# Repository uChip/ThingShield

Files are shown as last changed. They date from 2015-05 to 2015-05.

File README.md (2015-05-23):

# ThingShield
The [SparkFun Thing (WRL-13231)](https://www.sparkfun.com/products/13231) is a board for creating Internet of Things devices based on the ESP-8266 WiFi microcontroller.  This repo contains "shield" designs in the form factor and pinout of the Thing.

ThingShield_Bare is a set (schematic and board) of design files that have the basic board outline and pinout.  Use this as the start of your own shield design.  I have left a voltage regulator circuit on the board for power.  The regulator is easily deleted if it does not meet your needs.

ThingShield_Proto is a board with prototyping area.  Again there is a voltage regulator on the shield board.  The regulator can be omitted if your design does not need much current.  Instead you can draw power directly from the Thing board.

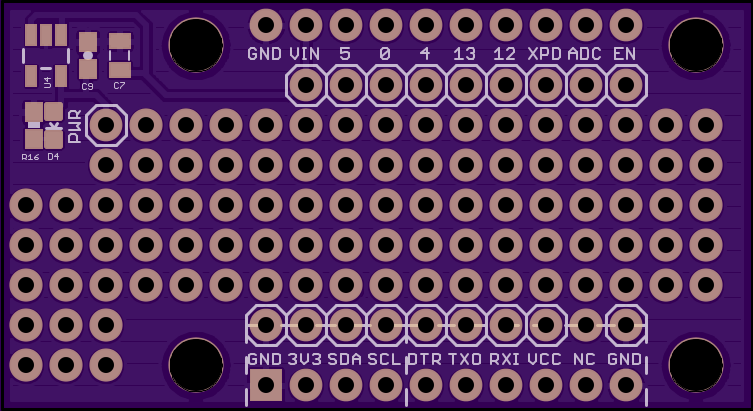
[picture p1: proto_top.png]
Thing Proto Board


Bare circuit boards of the proto shield can be ordered from [OSH Park](https://oshpark.com/shared_projects/OK6ncANs)

Boards propogate the CC license of the parent SparkFun board.  No liability accepted.

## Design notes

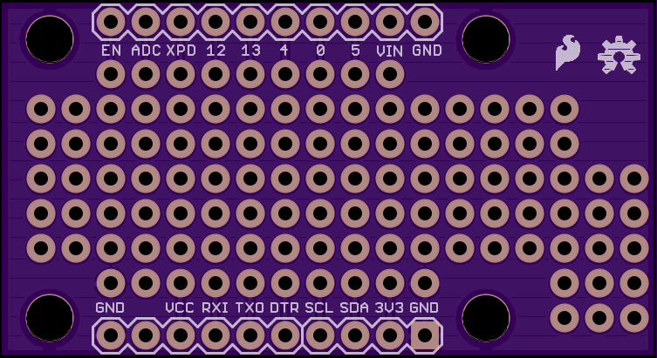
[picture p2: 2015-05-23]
proto_bottom.png

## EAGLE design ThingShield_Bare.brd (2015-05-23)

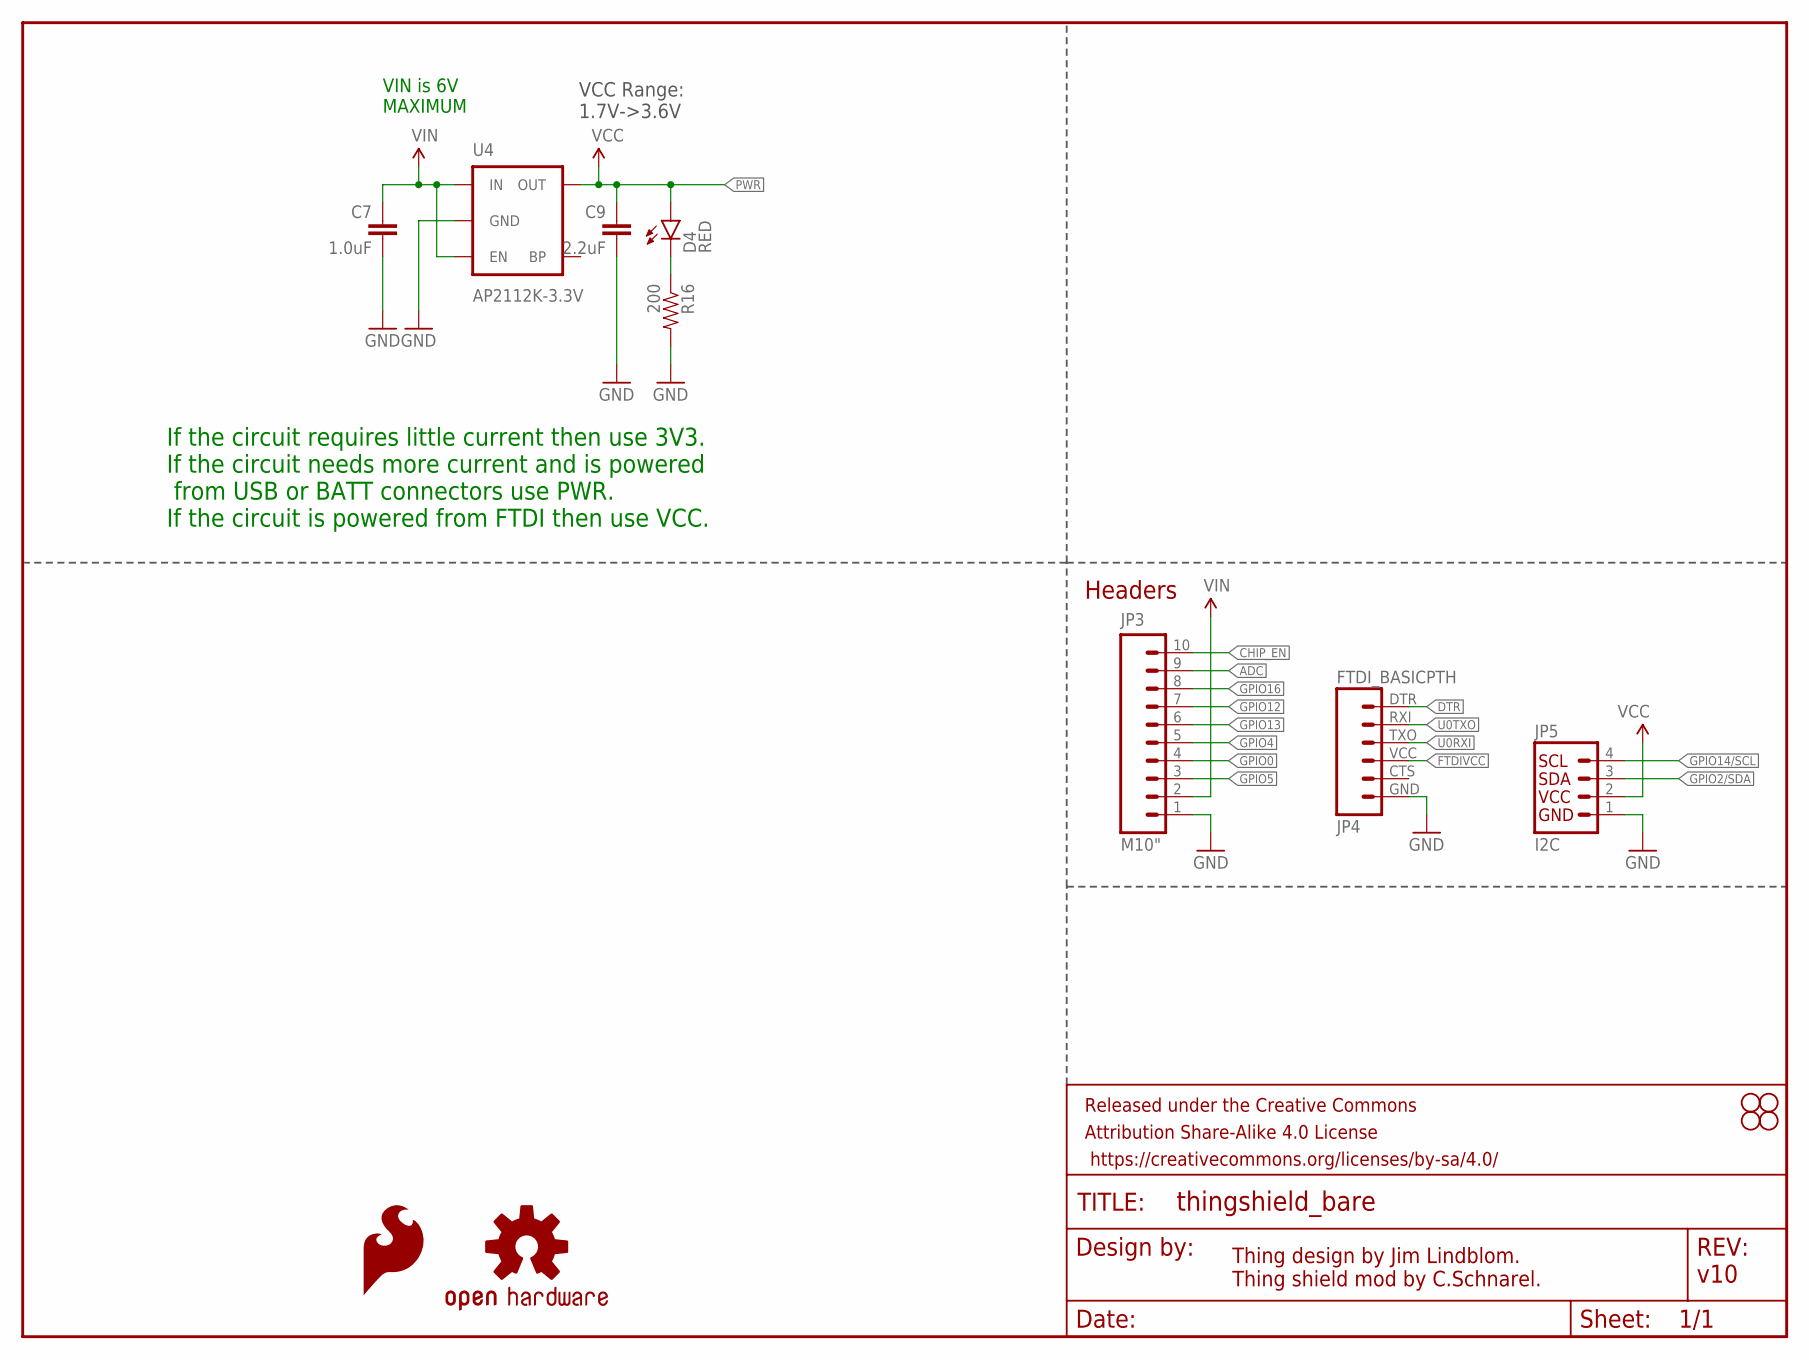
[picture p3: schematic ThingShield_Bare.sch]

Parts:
C7: 1.0uF; 0805
C9: 2.2uF; 0603-CAP
D4: RED; LED-0603
FRAME1: FRAME-LETTER; CREATIVE_COMMONS
JP3: M10"; 1X10
JP4: FTDI_BASICPTH; FTDI_BASIC
JP5: I2C; 1X04
LOGO3: SFE_LOGO_FLAME.1_INCH; SFE_LOGO_FLAME_.1
LOGO4: OSHW-LOGOS; OSHW-LOGO-S
R16: 200; 0603-RES
STANDOFF1, STANDOFF2, STANDOFF3, STANDOFF4: STAND-OFF
U4: AP2112K-3.3V; SOT23-5

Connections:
ADC: JP3.9
CHIP_EN: JP3.10
DTR: JP4.DTR (1)
FTDIVCC: JP4.VCC (4)
GND: C7.2, C9.2, JP3.1, JP4.GND (6), JP5.1, R16.2, U4.2 (GND)
GPIO0: JP3.4
GPIO2/SDA: JP5.3
GPIO4: JP3.5
GPIO5: JP3.3
GPIO12: JP3.7
GPIO13: JP3.6
GPIO14/SCL: JP5.4
GPIO16: JP3.8
unnamed: D4.C, R16.1
PWR: C9.1, D4.A, U4.5 (OUT)
U0RXI: JP4.TXO (3)
U0TXO: JP4.RXI (2)
VCC: JP5.2
VIN: C7.1, JP3.2, U4.1 (IN), U4.3 (EN)

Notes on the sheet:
Thing design by Jim Lindblom. Thing shield mod by C.Schnarel.
Headers
v10
VCC Range: 1.7V->3.6V
If the circuit requires little current then use 3V3. If the circuit needs more current and is powered from USB or BATT connectors use PWR. If the circuit is powered from FTDI then use VCC.
VIN is 6V MAXIMUM

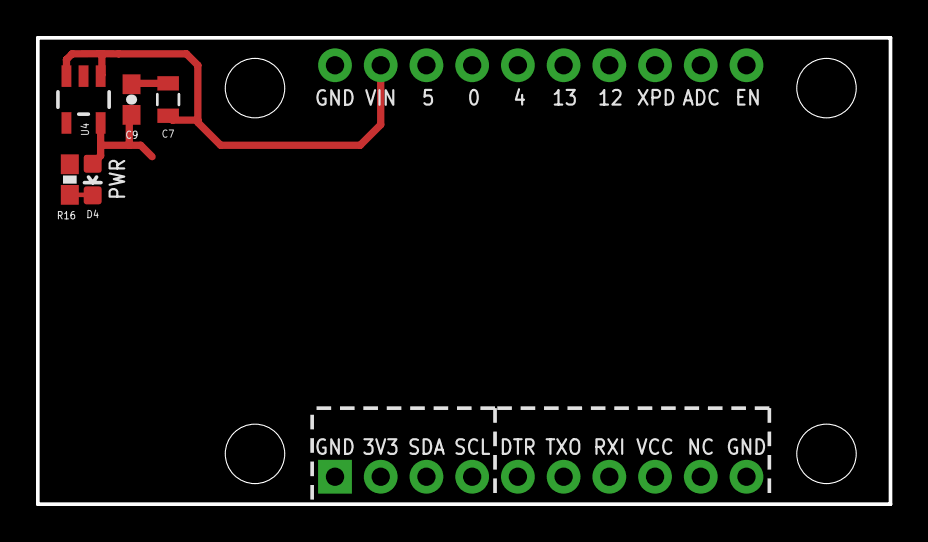
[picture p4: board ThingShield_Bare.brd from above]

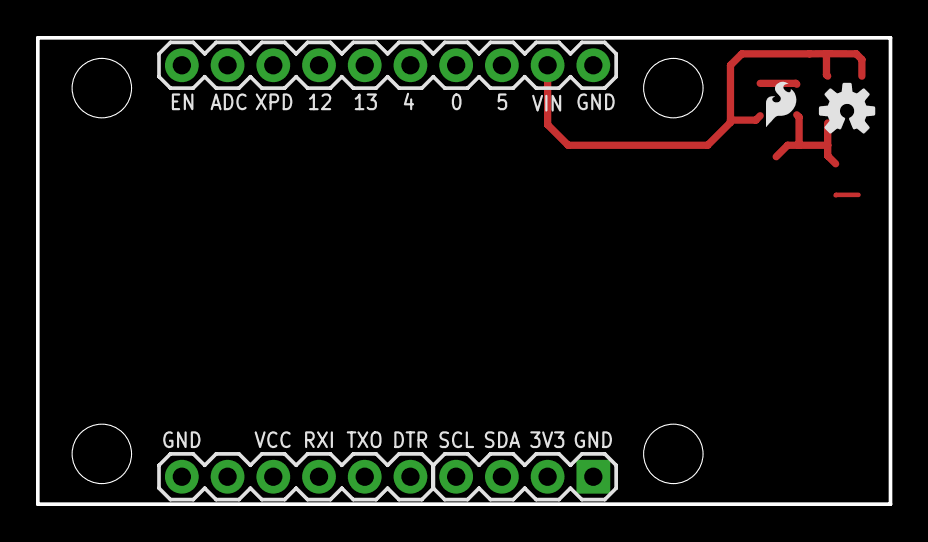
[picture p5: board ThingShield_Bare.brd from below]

Board: 2 copper layers, 47.4 x 25.9 mm, 15 parts (5 on the bottom side), 4 nets.

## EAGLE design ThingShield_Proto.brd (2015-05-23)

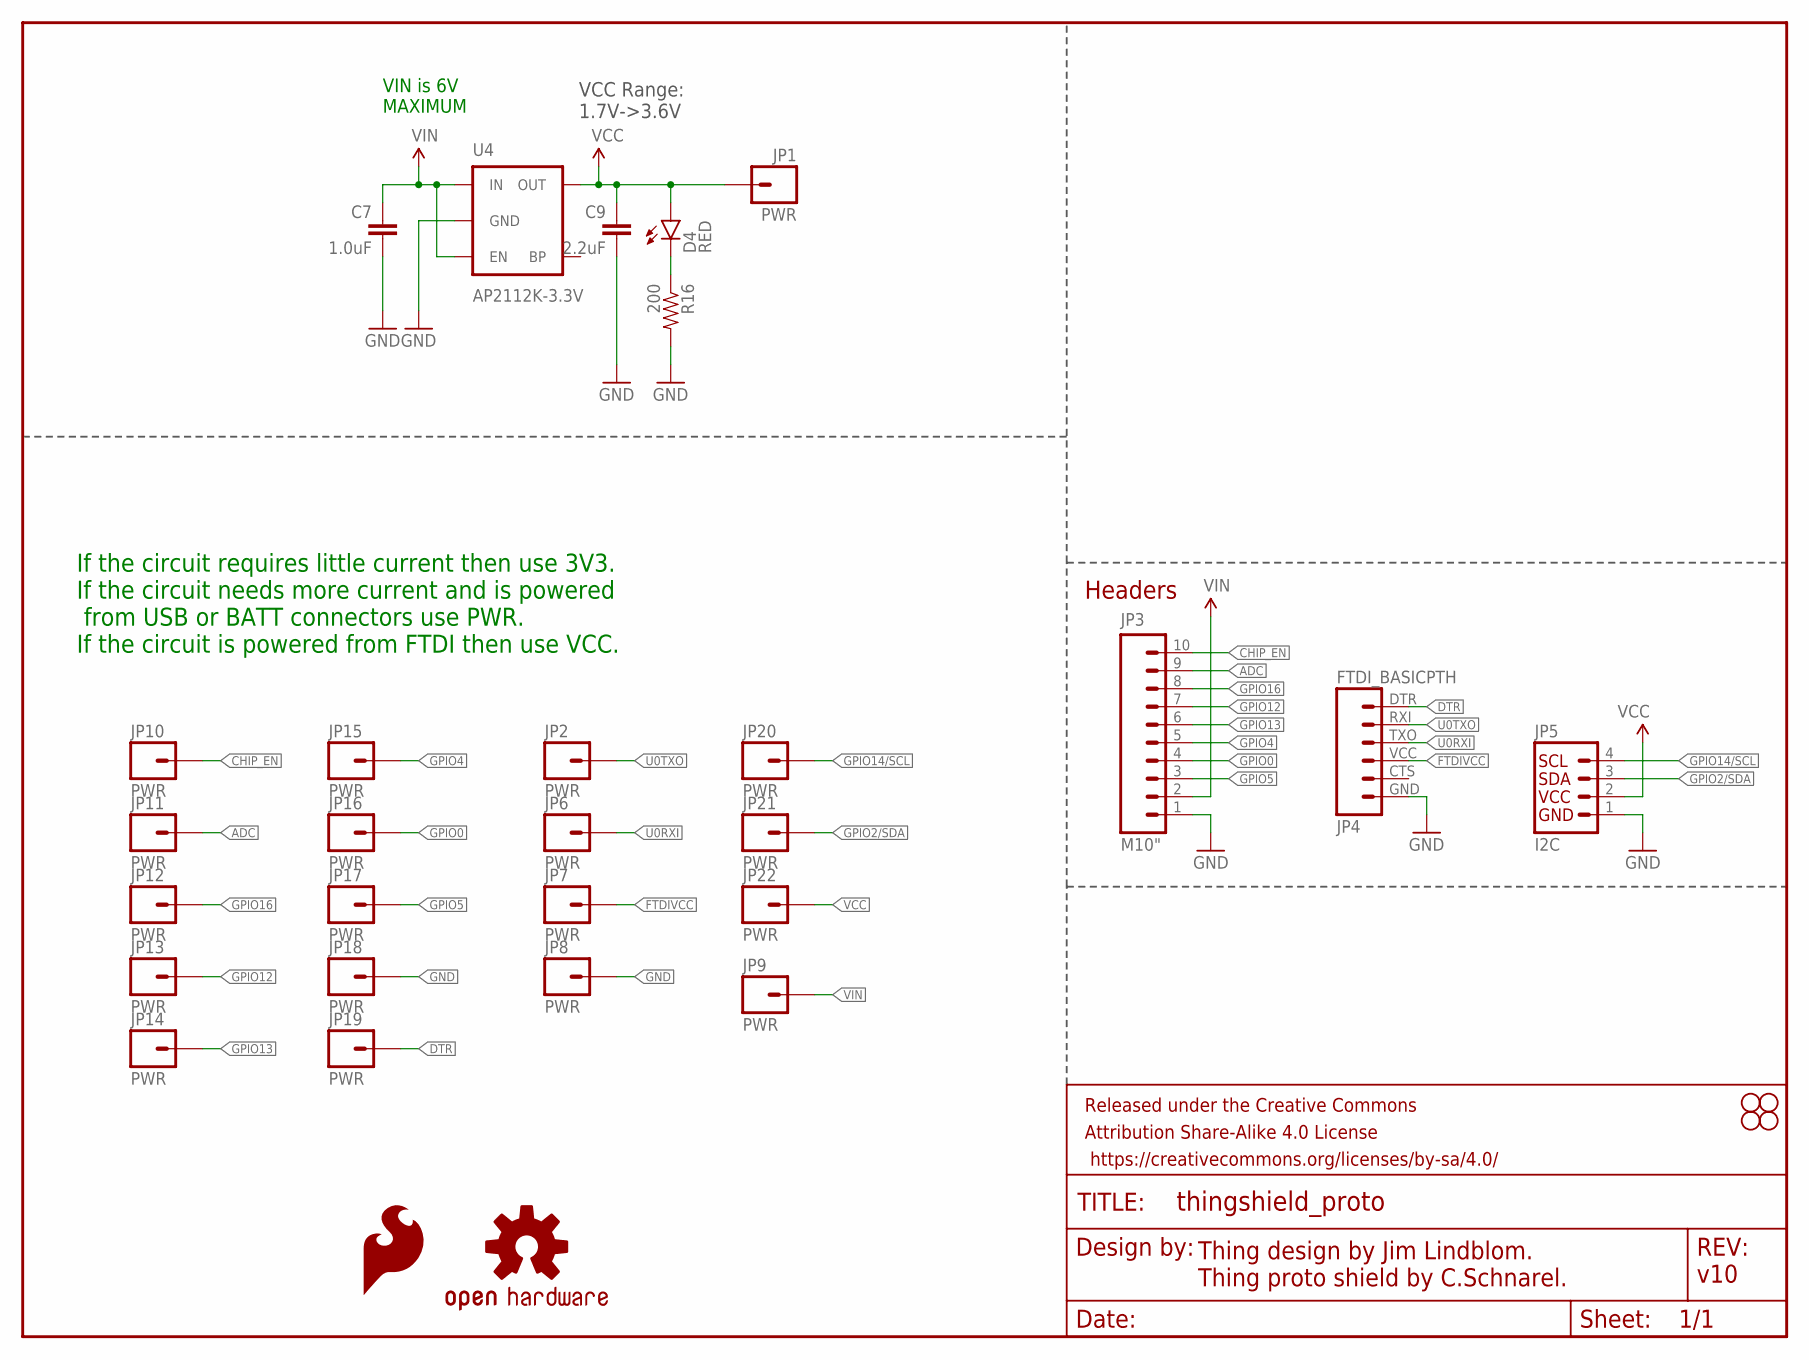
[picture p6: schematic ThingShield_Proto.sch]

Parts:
C7: 1.0uF; 0805
C9: 2.2uF; 0603-CAP
D4: RED; LED-0603
FRAME1: FRAME-LETTER; CREATIVE_COMMONS
JP1, JP2, JP6, JP7, JP8, JP9, JP10, JP11, JP12, JP13, JP14, JP15, JP16, JP17, JP18, JP19, JP20, JP21, JP22: PWR; 1X01
JP3: M10"; 1X10
JP4: FTDI_BASICPTH; FTDI_BASIC
JP5: I2C; 1X04
LOGO3: SFE_LOGO_FLAME.1_INCH; SFE_LOGO_FLAME_.1
LOGO4: OSHW-LOGOS; OSHW-LOGO-S
R16: 200; 0603-RES
STANDOFF1, STANDOFF2, STANDOFF3, STANDOFF4: STAND-OFF
U4: AP2112K-3.3V; SOT23-5

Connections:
ADC: JP3.9, JP11.1
CHIP_EN: JP3.10, JP10.1
DTR: JP4.DTR (1), JP19.1
FTDIVCC: JP4.VCC (4), JP7.1
GND: C7.2, C9.2, JP3.1, JP4.GND (6), JP5.1, JP8.1, JP18.1, R16.2, U4.2 (GND)
GPIO0: JP3.4, JP16.1
GPIO2/SDA: JP5.3, JP21.1
GPIO4: JP3.5, JP15.1
GPIO5: JP3.3, JP17.1
GPIO12: JP3.7, JP13.1
GPIO13: JP3.6, JP14.1
GPIO14/SCL: JP5.4, JP20.1
GPIO16: JP3.8, JP12.1
unnamed: D4.C, R16.1
PWR: C9.1, D4.A, JP1.1, U4.5 (OUT)
U0RXI: JP4.TXO (3), JP6.1
U0TXO: JP2.1, JP4.RXI (2)
VCC: JP5.2, JP22.1
VIN: C7.1, JP3.2, JP9.1, U4.1 (IN), U4.3 (EN)

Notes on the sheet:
Thing design by Jim Lindblom. Thing proto shield by C.Schnarel.
Headers
v10
VCC Range: 1.7V->3.6V
If the circuit requires little current then use 3V3. If the circuit needs more current and is powered from USB or BATT connectors use PWR. If the circuit is powered from FTDI then use VCC.
VIN is 6V MAXIMUM

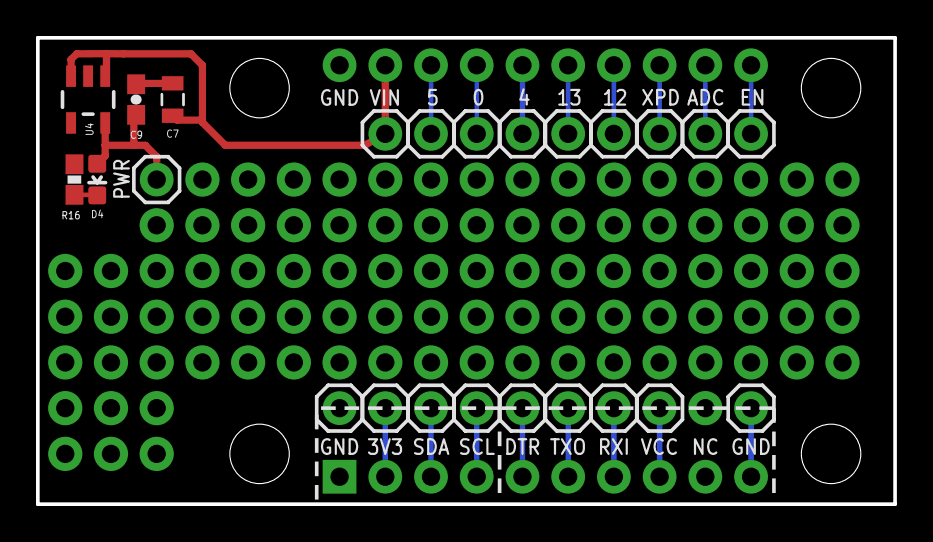
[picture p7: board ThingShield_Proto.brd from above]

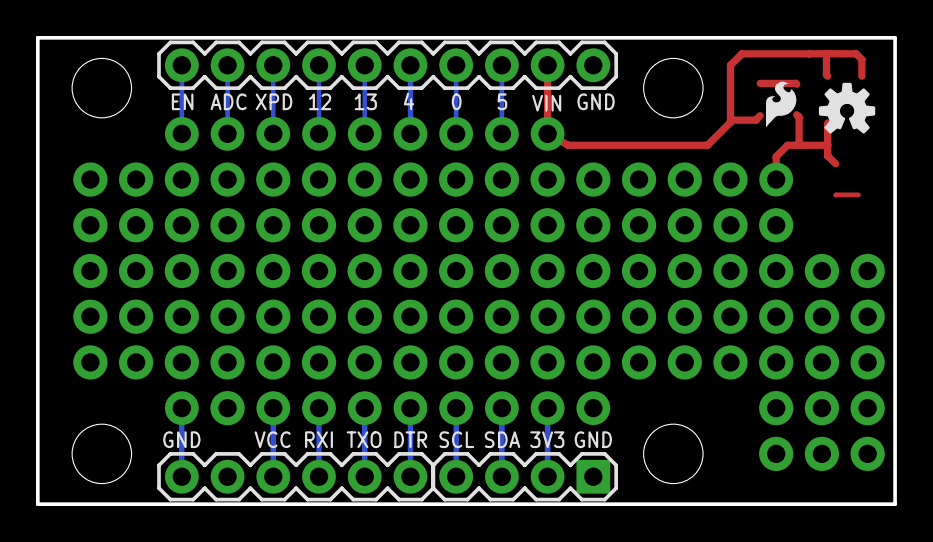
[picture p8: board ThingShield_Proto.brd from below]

Board: 2 copper layers, 47.6 x 25.9 mm, 34 parts (5 on the bottom side), 19 nets.

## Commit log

2015-05-23 Shield boards for SF Thing
    Bare board design in Eagle.
    Proto shield design in Eagle.
    [ThingShield_Bare.brd, ThingShield_Bare.sch, ThingShield_Proto.brd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]
2015-05-23 Create README.md
    First cut at README.
2015-05-23 First cut at module as a component
    NOT YET TESTED!
    [ThingShield_Bare.sch]

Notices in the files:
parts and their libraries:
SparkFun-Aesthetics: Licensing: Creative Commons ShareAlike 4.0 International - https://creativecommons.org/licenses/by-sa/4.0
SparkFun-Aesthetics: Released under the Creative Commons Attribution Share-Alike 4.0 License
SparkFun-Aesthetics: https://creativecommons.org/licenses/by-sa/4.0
